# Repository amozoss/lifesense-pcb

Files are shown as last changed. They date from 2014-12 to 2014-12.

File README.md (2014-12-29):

lifesense-pcb
=============

Senior project hardware 

CC3000 lib/footprint obtained here: https://github.com/mcous/kicad-lib/

### Software
The pcb software can be found at [lifesense-pcb-software](https://github.com/amozoss/lifesense-pcb-software)

### Images
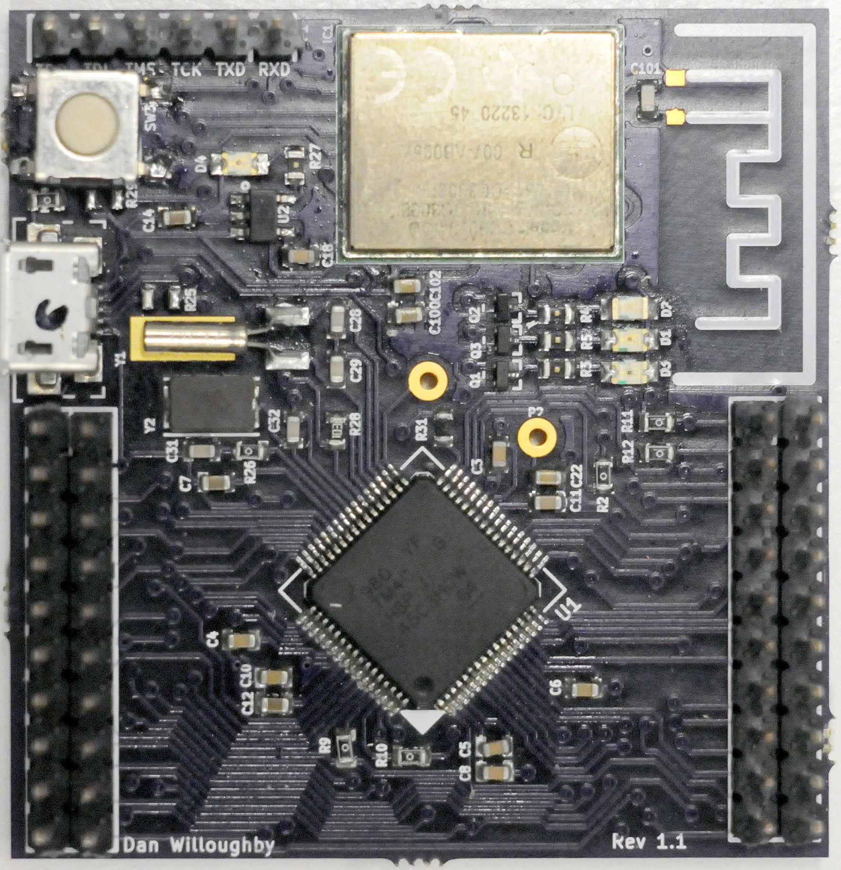
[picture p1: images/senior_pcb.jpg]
Fabricated PCB


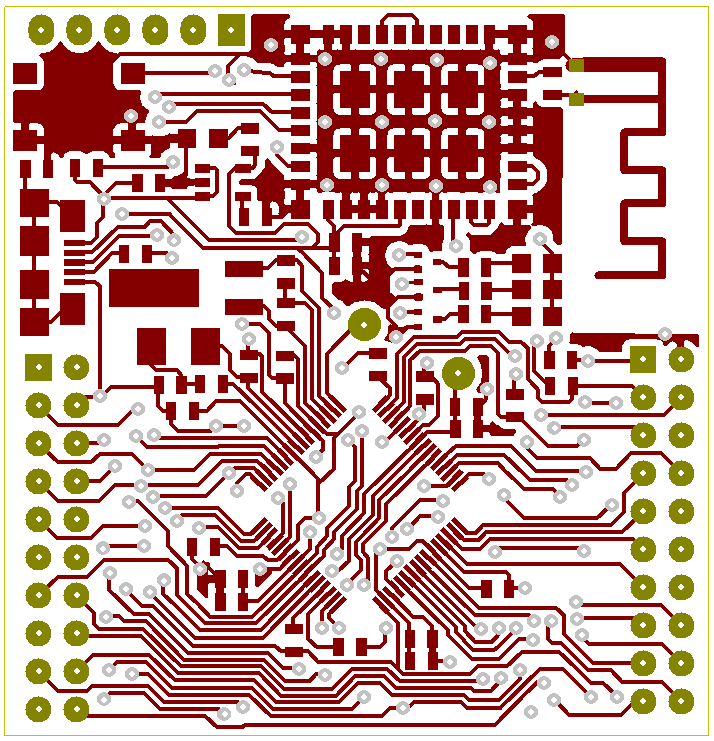
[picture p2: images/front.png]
Front


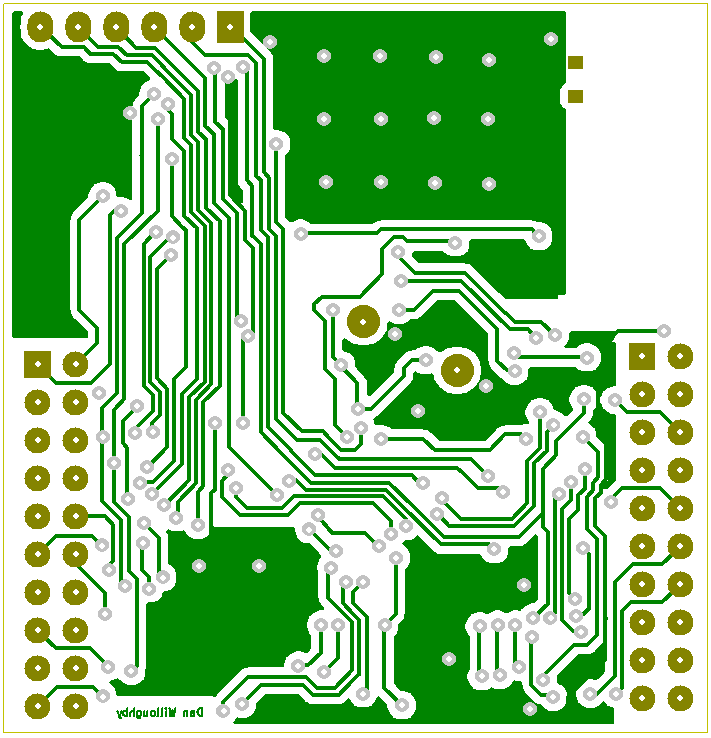
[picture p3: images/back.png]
Back


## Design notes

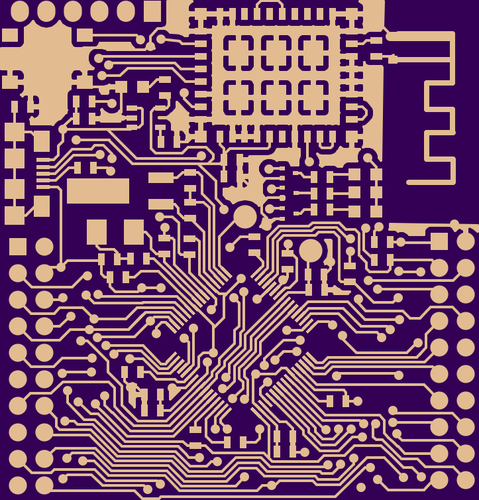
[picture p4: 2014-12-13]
docs/rev1.1_images/top_cop.png

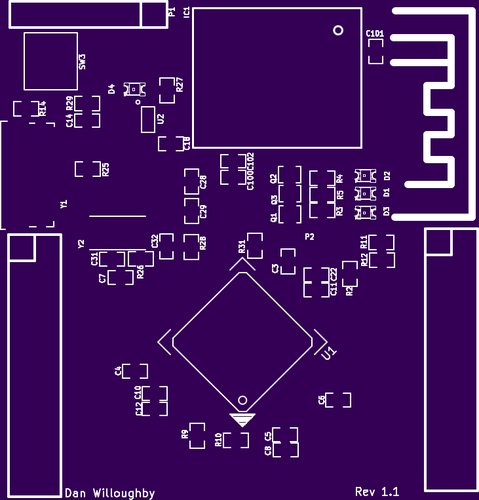
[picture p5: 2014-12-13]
docs/rev1.1_images/top_silk.png

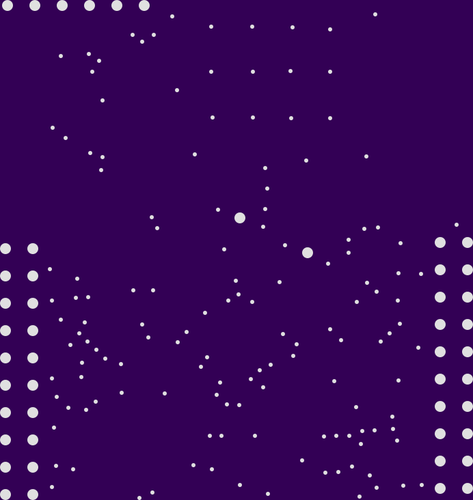
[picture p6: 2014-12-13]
docs/rev1.1_images/drill.png

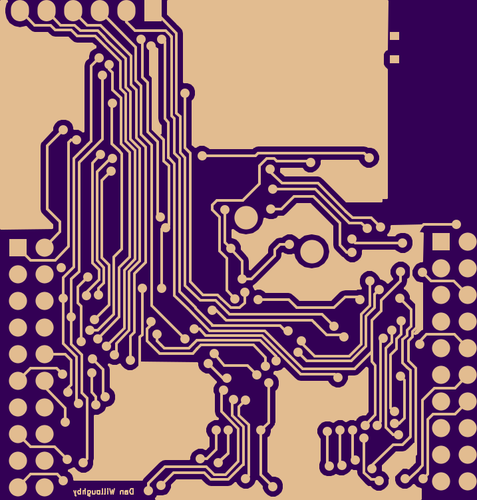
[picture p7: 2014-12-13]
docs/rev1.1_images/bot_cop.png

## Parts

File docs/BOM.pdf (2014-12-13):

Sheet1

Part | | Price quantity | Price | Quantity | Total price
TPS73633DBV | regulator | 1 | $0.00 | 1 | $0.00
AB26TRB-32.768KHZ-T | crystal | 1 | $0.54 | 1 | $0.54
ABM3-16.000MHZ-B2-T | crystal | 1 | $1.04 | 1 | $1.04
C7, C12, C14 | 1.0uF | 1 | $0.11 | 3 | $0.33
C31-32 | 10 pF | 1 | $0.10 | 2 | $0.20
C28-29 | 22pF | 1 | $0.10 | 2 | $0.20
C3, C5, C8, C18 | 0.01uF | 1 | $0.10 | 4 | $0.40
C4, C6, C10-11 | 0.1uF | 1 | $0.10 | 4 | $0.40
C22 | 2.2uF | 1 | $0.20 | 1 | $0.20
D4, D1 | green | 1 | $0.30 | 2 | $0.60
D2 | blue | 1 | $0.39 | 1 | $0.39
D3 | red | 1 | $0.32 | 1 | $0.32
J1, J3 | header 2x10 | 1 | $0.73 | 2 | $1.46
J9 | Mirco Usb | 1 | $1.02 | 1 | $1.02
Q1-3 | transistors | 1 | $0.15 | 3 | $0.45
RESET SW1, SW2 | switches | 1 | $0.76 | 1 | $0.76
R2, R9-12, R14, R26, R29(omit) | 0 ohm | 1 | $0.10 | 8 | $0.80
R28 | 10 k ohm | 1 | $0.10 | 1 | $0.10
R3-5, R27 | 330 ohm | 1 | $0.13 | 4 | $0.52
R31 | 1 M ohm | 1 | $0.10 | 1 | $0.10
C101 | 1pF
C102 | 4.7uF
c103 | 100nF

9.83

Footprint | Man. Part number
DONE
DONE
DONE
DONE | 250R14X105KV4T
DONE | 500R14N100JV4T
DONE | 500R14N220JV4T
DONE | 500R14W103KV4T
DONE | 160R14W104KV4T
DONE | GRM188R61C225KE15D
DONE | LTST-C171GKT
DONE | LTST-C170TBKT
DONE | LTST-C171KRKT
NO | 68602-116HLF
DONE | ZX62-AB-5PA(11)
DONE | DTC114EET1G
DONE | B3S-1000
DONE | ERJ-3GEY0R00V
DONE | RC0603JR-0710KL
DONE | KTR03EZPJ331
DONE | RC0603FR-071ML

Link
http://www.ti.com/product/TPS73633/samplebuy

http://www.digikey.com/product-search/en?KeyWords=ABM3-16.000MHZ-B2-T&WT.z_header=search_go

http://www.digikey.com/product-detail/en/500R14N100JV4T/709-1140-1-ND/1859472http://www.digikey.com/product-detail/en/500R14N220JV4T/709-1143-1-ND/1859475http://www.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

http://www.digikey.com/product-detail/en/ZX62-AB-5PA(11)/H11635CT-ND/1993370 http://www.digikey.com/product-detail/en/DTC114EET1G/DTC114EET1GOSCT-ND/1967041http://www.digikey.com/product-detail/en/B3S-1000/SW415-ND/20686http://www.digikey.com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

http://www.digikey.com/product-detail/en/250R14X105KV4T/709-1224-1-ND/2074916

http://www.digikey.com/product-detail/en/68000-436HLF/609-3505-ND/1487451

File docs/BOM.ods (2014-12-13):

Part |  | Price quantity | Price | Quantity | Total price | Footprint | Man. Part number | Link
TPS73633DBV | regulator | 1 | $0.00 | 1 | $0.00 | DONE |  | http://www.ti.com/product/TPS73633/samplebuy
AB26TRB-32.768KHZ-T | crystal | 1 | $0.54 | 1 | $0.54 | DONE |  | http://www.digikey.com/product-detail/en/AB26TRB-32.768KHZ-T/535-9033-1-ND/675581
ABM3-16.000MHZ-B2-T | crystal | 1 | $1.04 | 1 | $1.04 | DONE |  | http://www.digikey.com/product-search/en?KeyWords=ABM3-16.000MHZ-B2-T&WT.z_header=search_go
C7, C12, C14 | 1.0uF | 1 | $0.11 | 3 | $0.33 | DONE | 250R14X105KV4T | http://www.digikey.com/product-detail/en/250R14X105KV4T/709-1224-1-ND/2074916
C31-32 | 10 pF | 1 | $0.10 | 2 | $0.20 | DONE | 500R14N100JV4T | http://www.digikey.com/product-detail/en/500R14N100JV4T/709-1140-1-ND/1859472
C28-29 | 22pF | 1 | $0.10 | 2 | $0.20 | DONE | 500R14N220JV4T | http://www.digikey.com/product-detail/en/500R14N220JV4T/709-1143-1-ND/1859475
C3, C5, C8, C18 | 0.01uF | 1 | $0.10 | 4 | $0.40 | DONE | 500R14W103KV4T | http://www.digikey.com/product-detail/en/500R14W103KV4T/709-1160-1-ND/1859492
C4, C6, C10-11 | 0.1uF | 1 | $0.10 | 4 | $0.40 | DONE | 160R14W104KV4T | http://www.digikey.com/product-detail/en/160R14W104KV4T/709-1153-1-ND/1859485
C22 | 2.2uF | 1 | $0.20 | 1 | $0.20 | DONE | GRM188R61C225KE15D | http://www.digikey.com/product-detail/en/GRM188R61C225KE15D/490-3296-1-ND/702837
D4, D1 | green | 1 | $0.30 | 2 | $0.60 | DONE | LTST-C171GKT | http://www.digikey.com/product-detail/en/LTST-C171GKT/160-1423-1-ND/386792
D2 | blue | 1 | $0.39 | 1 | $0.39 | DONE | LTST-C170TBKT | http://www.digikey.com/product-detail/en/LTST-C170TBKT/160-1579-1-ND/564889
D3 | red | 1 | $0.32 | 1 | $0.32 | DONE | LTST-C171KRKT | http://www.digikey.com/product-detail/en/LTST-C171KRKT/160-1427-1-ND/386800
J1, J3 | header 2x10 | 1 | $0.73 | 2 | $1.46 | NO | 68602-116HLF | http://www.digikey.com/product-detail/en/68000-436HLF/609-3505-ND/1487451
J9 | Mirco Usb | 1 | $1.02 | 1 | $1.02 | DONE | ZX62-AB-5PA(11) | http://www.digikey.com/product-detail/en/ZX62-AB-5PA(11)/H11635CT-ND/1993370
Q1-3 | transistors | 1 | $0.15 | 3 | $0.45 | DONE | DTC114EET1G | http://www.digikey.com/product-detail/en/DTC114EET1G/DTC114EET1GOSCT-ND/1967041
RESET SW1, SW2 | switches | 1 | $0.76 | 1 | $0.76 | DONE | B3S-1000 | http://www.digikey.com/product-detail/en/B3S-1000/SW415-ND/20686
R2, R9-12, R14, R26, R29(omit) | 0 ohm | 1 | $0.10 | 8 | $0.80 | DONE | ERJ-3GEY0R00V | http://www.digikey.com/product-detail/en/ERJ-3GEY0R00V/P0.0GCT-ND/134711
R28 | 10 k ohm | 1 | $0.10 | 1 | $0.10 | DONE | RC0603JR-0710KL | http://www.digikey.com/product-detail/en/RC0603JR-0710KL/311-10KGRCT-ND/729647
R3-5, R27 | 330 ohm | 1 | $0.13 | 4 | $0.52 | DONE | KTR03EZPJ331 | http://www.digikey.com/product-detail/en/KTR03EZPJ331/RHM330AZCT-ND/2290050
R31 | 1 M ohm | 1 | $0.10 | 1 | $0.10 | DONE | RC0603FR-071ML | http://www.digikey.com/product-detail/en/RC0603FR-071ML/311-1.00MHRCT-ND/729791
C101 | 1pF
C102 | 4.7uF
c103 | 100nF
 |  |  |  |  | 9.83

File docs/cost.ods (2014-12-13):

 | Cost
parts | $83.62
Boards 1.0 | $17.85
flux | $7.95
Boards 1.1 | $17.85
Boards 1.1 | $17.85
total | 145.12

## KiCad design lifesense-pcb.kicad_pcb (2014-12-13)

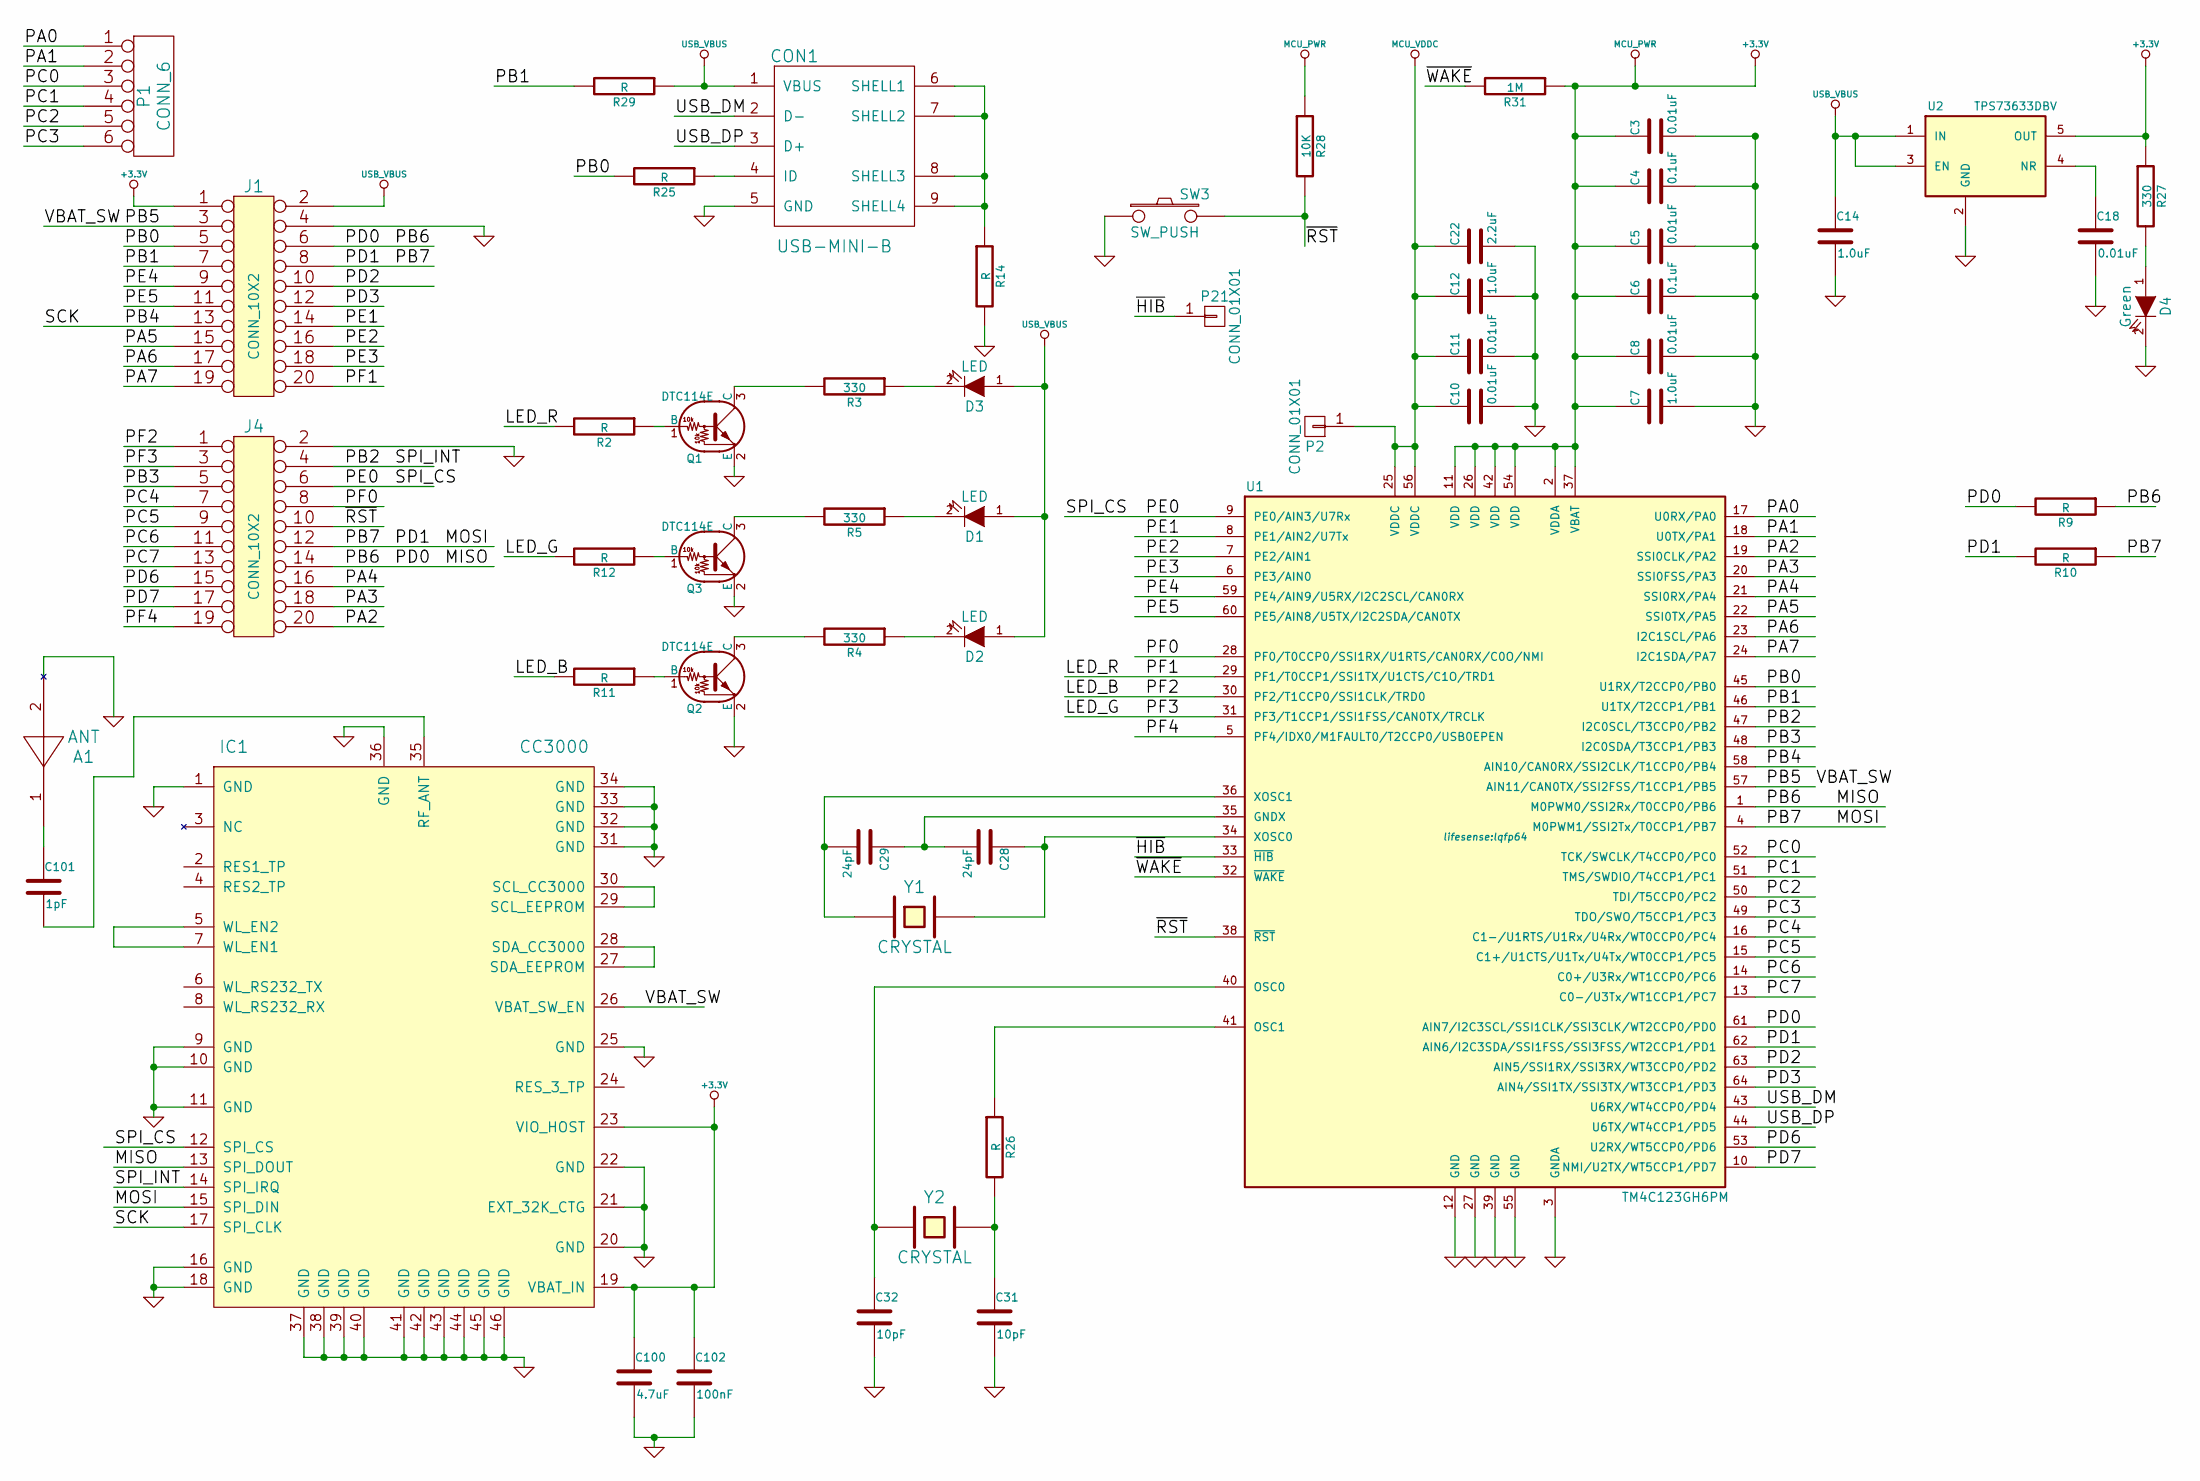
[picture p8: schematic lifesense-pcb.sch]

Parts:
A1: ANT; ant_Wigle_A2_4G
C3, C5, C8, C10, C11, C18: 0.01uF; SMD-0603_c
C4, C6: 0.1uF; SMD-0603_c
C7, C12, C14: 1.0uF; SMD-0603_c
C22: 2.2uF; SMD-0603_c
C28, C29: 24pF; SMD-0603_c
C31, C32: 10pF; SMD-0603_c
C100: 4.7uF; SMD-0603_c
C101: 1pF; SMD-0603_c
C102: 100nF; SMD-0603_c
CON1: USB-MINI-B; ZX62-AB-5PA(11)
D1, D2, D3: LED; LED-0805
D4: Green; LED-0805
IC1: CC3000; Manuf. Part CC3000MOD
J1, J4: CONN_10X2; Pin_Header_Straight_2x10
P1: CONN_6; Pin_Header_Straight_1x06
P2, P21: CONN_01X01; Pin_Header_Straight_1x01
Q1, Q2, Q3: DTC114E; DTC114EET1G
R2, R9, R10, R11, R12, R14, R25, R26, R29: R; SMD-0603_r
R3, R4, R5, R27: 330; SMD-0603_r
R28: 10K; SMD-0603_r
R31: 1M; SMD-0603_r
SW3: SW_PUSH
U1: TM4C123GH6PM; lqfp64
U2: TPS73633DBV
Y1: CRYSTAL; AB26TRB
Y2: CRYSTAL; ABM3

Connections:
/LED_B: J4.1, R11.2, U1.30 (PF2/T1CCP0/SSI1CLK/TRD0)
/LED_G: J4.3, R12.2, U1.31 (PF3/T1CCP1/SSI1FSS/CAN0TX/TRCLK)
/LED_R: J1.20, R2.2, U1.29 (PF1/T0CCP1/SSI1TX/U1CTS/C1O/TRD1)
/MISO: IC1.13 (SPI_DOUT), J1.6, J4.14, R9.1, R9.2, U1.1 (M0PWM0/SSI2Rx/T0CCP0/PB6), U1.61 (AIN7/I2C3SCL/SSI1CLK/SSI3CLK/WT2CCP0/PD0)
/MOSI: IC1.15 (SPI_DIN), J1.8, J4.12, R10.1, R10.2, U1.4 (M0PWM1/SSI2Tx/T0CCP1/PB7), U1.62 (AIN6/I2C3SDA/SSI1FSS/SSI3FSS/WT2CCP1/PD1)
/PA0: P1.1, U1.17 (U0RX/PA0)
/PA1: P1.2, U1.18 (U0TX/PA1)
/PA2: J4.20, U1.19 (SSI0CLK/PA2)
/PA3: J4.18, U1.20 (SSI0FSS/PA3)
/PA4: J4.16, U1.21 (SSI0RX/PA4)
/PA5: J1.15, U1.22 (SSI0TX/PA5)
/PA6: J1.17, U1.23 (I2C1SCL/PA6)
/PA7: J1.19, U1.24 (I2C1SDA/PA7)
/PB0: J1.5, R25.2, U1.45 (U1RX/T2CCP0/PB0)
/PB1: J1.7, R29.2, U1.46 (U1TX/T2CCP1/PB1)
/PB2: IC1.14 (SPI_IRQ), J4.4, U1.47 (I2C0SCL/T3CCP0/PB2)
/PB3: J4.5, U1.48 (I2C0SDA/T3CCP1/PB3)
/PB4: IC1.17 (SPI_CLK), J1.13, U1.58 (AIN10/CAN0RX/SSI2CLK/T1CCP0/PB4)
/PB5: IC1.26 (VBAT_SW_EN), J1.3, U1.57 (AIN11/CAN0TX/SSI2FSS/T1CCP1/PB5)
/PC0: P1.3, U1.52 (TCK/SWCLK/T4CCP0/PC0)
/PC1: P1.4, U1.51 (TMS/SWDIO/T4CCP1/PC1)
/PC2: P1.5, U1.50 (TDI/T5CCP0/PC2)
/PC3: P1.6, U1.49 (TDO/SWO/T5CCP1/PC3)
/PC4: J4.7, U1.16 (C1-/U1RTS/U1Rx/U4Rx/WT0CCP0/PC4)
/PC5: J4.9, U1.15 (C1+/U1CTS/U1Tx/U4Tx/WT0CCP1/PC5)
/PC6: J4.11, U1.14 (C0+/U3Rx/WT1CCP0/PC6)
/PC7: J4.13, U1.13 (C0-/U3Tx/WT1CCP1/PC7)
/PD2: J1.10, U1.63 (AIN5/SSI1RX/SSI3RX/WT3CCP0/PD2)
/PD3: J1.12, U1.64 (AIN4/SSI1TX/SSI3TX/WT3CCP1/PD3)
/PD6: J4.15, U1.53 (U2RX/WT5CCP0/PD6)
/PD7: J4.17, U1.10 (NMI/U2TX/WT5CCP1/PD7)
/PE0: IC1.12 (SPI_CS), J4.6, U1.9 (PE0/AIN3/U7Rx)
/PE1: J1.14, U1.8 (PE1/AIN2/U7Tx)
/PE2: J1.16, U1.7 (PE2/AIN1)
/PE3: J1.18, U1.6 (PE3/AIN0)
/PE4: J1.9, U1.59 (PE4/AIN9/U5RX/I2C2SCL/CAN0RX)
/PE5: J1.11, U1.60 (PE5/AIN8/U5TX/I2C2SDA/CAN0TX)
/PF0: J4.8, U1.28 (PF0/T0CCP0/SSI1RX/U1RTS/CAN0RX/C0O/NMI)
/PF4: J4.19, U1.5 (PF4/IDX0/M1FAULT0/T2CCP0/USB0EPEN)
/USB_DM: CON1.2 (D-), U1.43 (U6RX/WT4CCP0/PD4)
/USB_DP: CON1.3 (D+), U1.44 (U6TX/WT4CCP1/PD5)
/~HIB~: P21.1, U1.33 (~HIB~)
/~RST~: J4.10, R28.2, SW3.2, U1.38 (~RST~)
/~WAKE~: R31.2, U1.32 (~WAKE~)
GND: A1.2, C3.2, C4.2, C5.2, C6.2, C7.2, C8.2, C10.2, C11.2, C12.2, C14.2, C18.2, C22.2, C31.2, C32.2, C100.2, C102.2, CON1.5 (GND), D4.2 (K), IC1.1 (GND), IC1.9 (GND), IC1.10 (GND), IC1.11 (GND), IC1.16 (GND), IC1.18 (GND), IC1.20 (GND), IC1.21 (EXT_32K_CTG), IC1.22 (GND), IC1.25 (GND), IC1.31 (GND), IC1.32 (GND), IC1.33 (GND), IC1.34 (GND), IC1.36 (GND), IC1.37 (GND), IC1.38 (GND), IC1.39 (GND), IC1.40 (GND), IC1.41 (GND), IC1.42 (GND), IC1.43 (GND), IC1.44 (GND), IC1.45 (GND), IC1.46 (GND), J1.4, J4.2, Q1.2 (E), Q2.2 (E), Q3.2 (E), R14.2, SW3.1, U1.3 (GNDA), U1.12 (GND), U1.27 (GND), U1.39 (GND), U1.55 (GND), U2.2 (GND)
MCU_PWR: C3.1, C4.1, C5.1, C6.1, C7.1, C8.1, C100.1, C102.1, IC1.19 (VBAT_IN), IC1.23 (VIO_HOST), J1.1, R27.1, R28.1, R31.1, U1.2 (VDDA), U1.11 (VDD), U1.26 (VDD), U1.37 (VBAT), U1.42 (VDD), U1.54 (VDD), U2.5 (OUT)
MCU_VDDC: C10.1, C11.1, C12.1, C22.1, P2.1, U1.25 (VDDC), U1.56 (VDDC)
unnamed: A1.1, C101.1
unnamed: C18.1, U2.4 (NR)
unnamed: C28.1, U1.34 (XOSC0), Y1.2
unnamed: C28.2, C29.1, U1.35 (GNDX)
unnamed: C29.2, U1.36 (XOSC1), Y1.1
unnamed: C31.1, R26.2, Y2.2
unnamed: C32.1, U1.40 (OSC0), Y2.1
unnamed: C101.2, IC1.35 (RF_ANT)
unnamed: CON1.4 (ID), R25.1
unnamed: CON1.6 (SHELL1), CON1.7 (SHELL2), CON1.8 (SHELL3), CON1.9 (SHELL4), R14.1
unnamed: D1.2 (K), R5.1
unnamed: D2.2 (K), R4.1
unnamed: D3.2 (K), R3.1
unnamed: D4.1 (A), R27.2
unnamed: IC1.5 (WL_EN2), IC1.7 (WL_EN1)
unnamed: IC1.27 (SDA_EEPROM), IC1.28 (SDA_CC3000)
unnamed: IC1.29 (SCL_EEPROM), IC1.30 (SCL_CC3000)
unnamed: Q1.1 (B), R2.1
unnamed: Q1.3 (C), R3.2
unnamed: Q2.1 (B), R11.1
unnamed: Q2.3 (C), R4.2
unnamed: Q3.1 (B), R12.1
unnamed: Q3.3 (C), R5.2
unnamed: R26.1, U1.41 (OSC1)
USB_VBUS: C14.1, CON1.1 (VBUS), D1.1 (A), D2.1 (A), D3.1 (A), J1.2, R29.1, U2.1 (IN), U2.3 (EN)

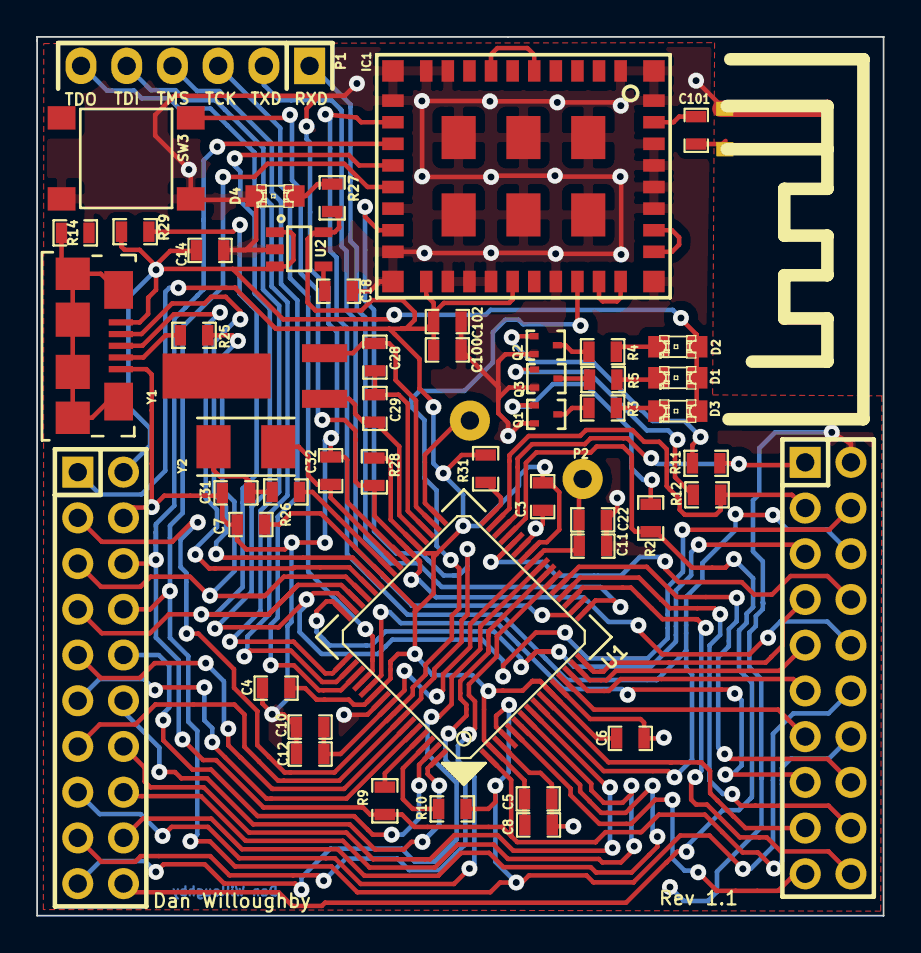
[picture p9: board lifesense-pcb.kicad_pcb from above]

Board: 2 copper layers, 47.0 x 48.8 mm, 54 parts (0 on the bottom side), 72 nets.

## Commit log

2014-05-31 added resistor
    [lifesense-pcb.sch]
2014-06-09 Adding msp430 and cc3000 footprint.
    [lifesense-pcb.kicad_pcb, lifesense-pcb.sch]
2014-06-12 moving to tiva-c TM4C123GH6PM chip
    [lifesense-pcb.kicad_pcb, lifesense-pcb.sch]
2014-08-29 only 2 things wrong, missing button
    [BOM.ods, lifesense-pcb.kicad_pcb, lifesense-pcb.sch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]
2014-09-12 finished board 1.0
    [BOM.ods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]
2014-12-13 fabricated 1.1 version
    [BOM.ods, cost.ods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]
